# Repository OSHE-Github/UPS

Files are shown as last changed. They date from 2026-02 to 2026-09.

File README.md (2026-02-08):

# UPS

Uninterruptible Power Supply Hat for Raspberry Pi

This is still very early in the design phase and is not suitable for use.

*･゜ﾟ･*:.｡..｡.:*･'(*ﾟ▽ﾟ*)'･*:.｡. .｡.:*･゜ﾟ･*

## Copyright

- All code is licensed under the GPL 3.0 or later. You can view a copy of this license in LICENSE.code
- All hardware computer aided design "CAD files" are licensed under the CERN-OHL-S license. A copy of this license can be found in LICENSE.cad
- Some footprints are provided by the manufacturer or a third party source. They are licensed under their respective licenses.

Which licenses apply to which files will be clarified in a later commit. If you have questions please contact us.

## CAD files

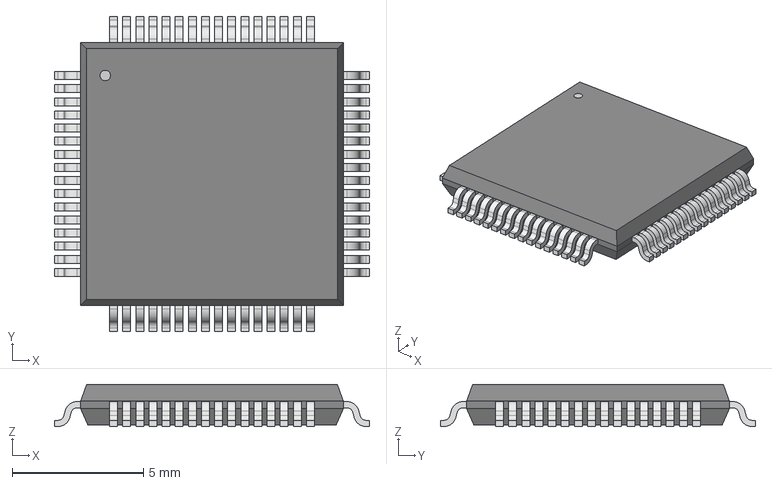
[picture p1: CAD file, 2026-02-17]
bloat/ul_STM32L152RCT6 (1)/LQFP64-10x10mm.step
12.0 x 12.0 x 1.60 mm

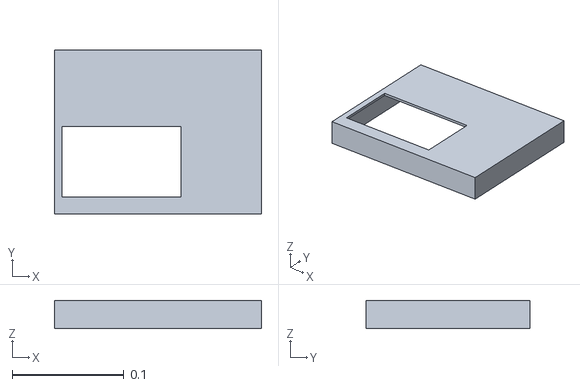
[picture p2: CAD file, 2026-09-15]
ecad/UPS-Case-V1-P2.stl
0.185 x 0.147 x 0.0254

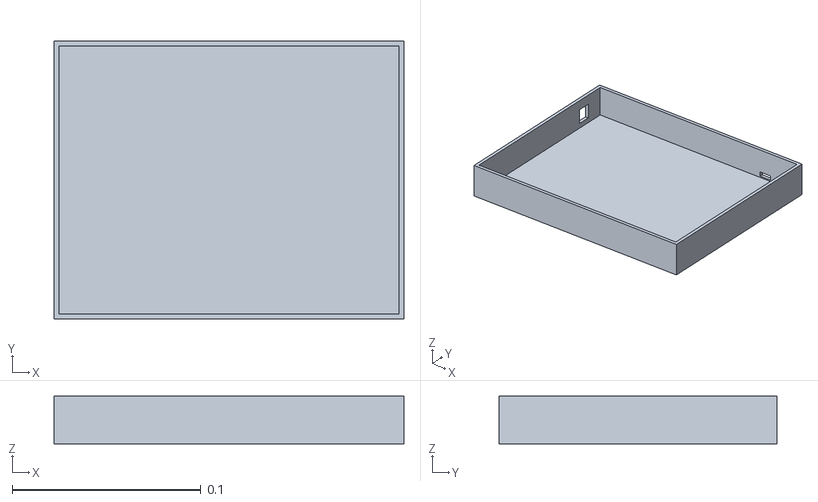
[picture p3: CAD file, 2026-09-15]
ecad/UPS-Case-V1-P1.stl
0.185 x 0.147 x 0.0254

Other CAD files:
bloat/ul_STM32L152RCT6 (1)/LQFP64-10x10mm.iges
bloat/ul_STM32L152RCT6 (1)/LQFP64-10x10mm.stl

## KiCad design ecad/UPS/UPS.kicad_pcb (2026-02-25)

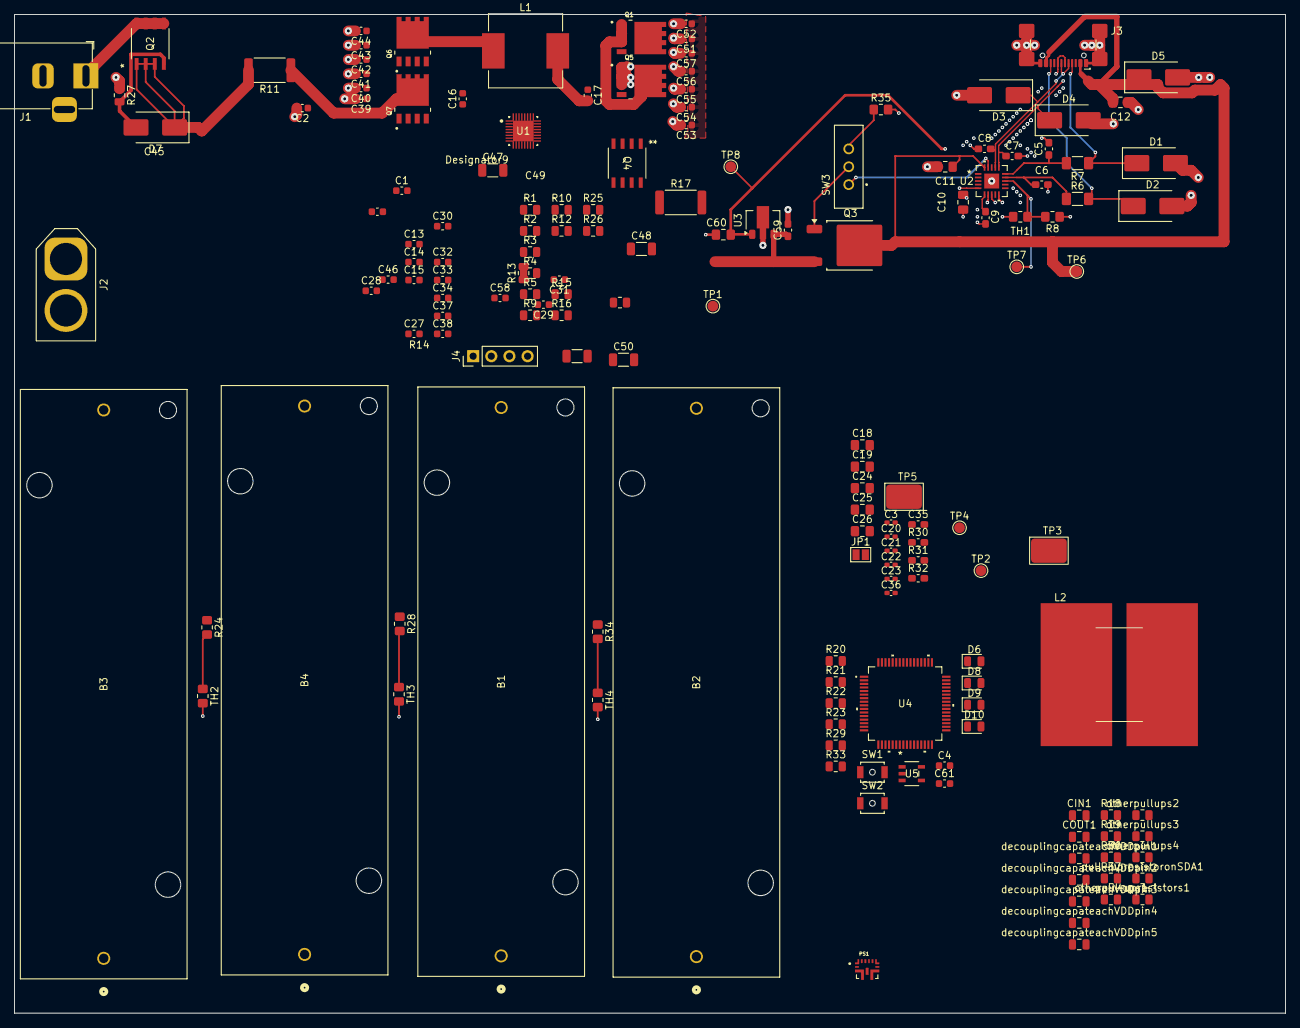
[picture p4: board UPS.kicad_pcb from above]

Board: 4 copper layers, 177.8 x 139.7 mm, 160 parts (0 on the bottom side), 77 nets.

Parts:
B1, B2, B3, B4: 1121; 1121_KEY
C1, C2: 100pF; C_0603_1608Metric
C3, C20, C21: .1uF; C_0402_1005Metric_Pad0.74x0.62mm_HandSolder
C4, C61: 0.1uf; C_0603_1608Metric
C5, C6: 390pF; C_0603_1608Metric_Pad1.08x0.95mm_HandSolder
C7, C8: 1nF; C_0603_1608Metric_Pad1.08x0.95mm_HandSolder
C9: 470pF; C_0603_1608Metric_Pad1.08x0.95mm_HandSolder
C10, C11, C12: 4.7uF; C_0805_2012Metric_Pad1.18x1.45mm_HandSolder
C13, C15: 33nF; C_0603_1608Metric
C14, C45: 10nF; C_0603_1608Metric
C16: 47nF; C_0603_1608Metric
C17: 47 nF; C_0603_1608Metric
C18, C19: 10uF; C_0805_2012Metric_Pad1.18x1.45mm_HandSolder
C22: 3.9nF; C_0402_1005Metric_Pad0.74x0.62mm_HandSolder
C23: 80pF; C_0402_1005Metric_Pad0.74x0.62mm_HandSolder
C24, C25, C26: 22uF; C_0805_2012Metric_Pad1.18x1.45mm_HandSolder
C27: 1uF; C_0603_1608Metric
C28: 15pF; C_0603_1608Metric
C29: 33pF; C_0603_1608Metric
C30: 1200 pF; C_0603_1608Metric
C31: 3.3nF; C_0603_1608Metric
C32: .1µF; C_0603_1608Metric
C33, C37, C39, C40, C41, C42, C43, C44, C51, C52, C53, C54, C55, C56, C57: 10µF; C_0603_1608Metric
C34, C38: 1µF; C_0603_1608Metric
C35: 2.2uF; C_0603_1608Metric_Pad1.08x0.95mm_HandSolder
C36: 1pF; C_0402_1005Metric_Pad0.74x0.62mm_HandSolder
C46: 1 nF; C_0603_1608Metric
C47, C48, C49, C50: 22µF; C_1206_3216Metric
C58: 2.2µF; C_0603_1608Metric
C59: 330nF; C_0603_1608Metric_Pad1.08x0.95mm_HandSolder
C60: 100nF; C_0805_2012Metric_Pad1.18x1.45mm_HandSolder
CIN1: 1uf; C_0805_2012Metric
COUT1: 1uf; C_0805_2012Metric
D1, D2: 6V; D_SMB_Handsoldering
D3, D4: 3.5V; D_SMB_Handsoldering
D5: 13V; D_SMB_Handsoldering
D6, D8, D9, D10: LED; LED_0805_2012Metric
D7: D_Zener; D_SMB_Handsoldering
J1: Barrel_Jack; BarrelJack_Horizontal
J2: Conn_01x02_Socket; AMASS_XT60-F_1x02_P7.20mm_Vertical
J3: USB_C_Receptacle_USB2.0_16P; USB_C_Receptacle_GCT_USB4110
J4: PROG; PinHeader_1x04_P2.54mm_Vertical
JP1: SolderJumper_2_Open; SolderJumper-2_P1.3mm_Open_Pad1.0x1.5mm
L1: 2.2µH; L_Vishay_IHLP-4040
L2: 4.7uH; IND_ETQP8M4R7JFA
PS1: TPS61288LRQQR; CONV_TPS61288LRQQR
Q1, Q5, Q6, Q7: CSD18540Q5B; TRANS_CSD18540Q5B
Q2: Q_PMOS_DGS; FDS6681Z_OSI-M
Q3: IRLR7843TRPBF; TO-252-2
Q4: Q_PMOS_DGS; FDS6681Z_OSI
R1: 140k; R_0805_2012Metric
R2, R14, R36, R37: 10k; R_0805_2012Metric
R3: 56k; R_0805_2012Metric
R4, R19, R27: 100k; R_0805_2012Metric
R5, R15, R16: 10; R_0805_2012Metric
R6, R7: 2; R_1206_3216Metric_Pad1.30x1.75mm_HandSolder
R8, R24, R28, R34, R35: 68.1k; R_0805_2012Metric_Pad1.20x1.40mm_HandSolder
R9, R10: 4.99; R_0805_2012Metric
R11, R17: .01; R_2512_6332Metric
R12: 2.2; R_0805_2012Metric
R13: 16.9k; R_0805_2012Metric
R18: 15k; R_0805_2012Metric
R20, R21, R22, R33: 1.5K; R_0805_2012Metric
R23, R29: 10K; R_0805_2012Metric
R25: 60k; R_0805_2012Metric
R26: 20k; R_0805_2012Metric
R30: 8.25k; C_0603_1608Metric_Pad1.08x0.95mm_HandSolder
R31: 14.3k; C_0603_1608Metric_Pad1.08x0.95mm_HandSolder
R32: 107k; C_0603_1608Metric_Pad1.08x0.95mm_HandSolder
SW1, SW2: SW_Push; SW_SPST_B3U-1000P-B
SW3: SW_DPDT_x2; SW_EG1218
TH1, TH2, TH3, TH4: B57471V2104J062; R_0805_2012Metric_Pad1.20x1.40mm_HandSolder
TP1: 5vTest; TestPoint_Pad_D1.5mm
TP2: AGNDTest; TestPoint_Pad_D1.5mm
TP3: PGNDTest; TespointBig
TP4: Enable; TestPoint_Pad_D1.5mm
TP5: Vin; TespointBig
TP6: VBus; TestPoint_Pad_D1.5mm
TP7: NTC1; TestPoint_Pad_D1.5mm
TP8: 5V_REG; TestPoint_Pad_D1.5mm
U1: BQ25730RSNR; RSN0032B-IPC_A
U2: MPQ5031GRE-0001-AEC1-P; QFN-20_MPQ5031_MNP
U3: L78L05_SOT89; SOT-89-3
U4: STM32L152RCT6; LQFP64-10x10mm
U5: AP2112K-3.3TRG1; SOT_RG1_DIO
decouplingcapateachVDDpin1, decouplingcapateachVDDpin2, decouplingcapateachVDDpin3, decouplingcapateachVDDpin4, decouplingcapateachVDDpin5: 100nF; C_0805_2012Metric
otherpullups1, otherpullups2, otherpullups3, otherpullups4: 10k; R_0805_2012Metric
pull-upresistoronSDA1: 4.7k; R_0805_2012Metric
pull-upresistors1: 4.7k; R_0805_2012Metric

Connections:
3.3V: C61.2, COUT1.1, R19.2, R29.1, R36.2, R37.2, SW1.1, U4.13 (VDDA), U4.19 (VDD_4), U4.32 (VDD_1), U4.48 (VDD_2), U4.64 (VDD_3), U5.5 (VOUT), decouplingcapateachVDDpin1.2, decouplingcapateachVDDpin2.2, decouplingcapateachVDDpin3.2, decouplingcapateachVDDpin4.2, decouplingcapateachVDDpin5.2, otherpullups1.2, otherpullups2.2, otherpullups3.2, otherpullups4.2, pull-upresistoronSDA1.1, pull-upresistors1.1
+3.3V: J4.1, R24.1, R28.1, R34.1
+5V: C10.1, C60.2, CIN1.1, R8.1, TP8.1, U2.5 (I2C_MODE), U2.7 (VCC), U3.1 (OUT), U5.1 (VIN), U5.3 (EN)
/BoostConvertor/VSYS: C49.1, C50.1
/BoostConvertor/Vcc: C35.1, PS1.6 (EN), PS1.11 (VCC), TP4.1
/Charger/CMPIN: R18.1, R19.1, U1.14 (CMPIN)
/Charger/OTG/VAP: U1.5 (OTG_VAP), U4.22 (PA6), otherpullups3.1
/Charger/PROCHOT_N: U1.11 (PROCHOT_N), U4.14 (PA0-WKUP1), otherpullups1.1
/Charger/bat_th1: R24.2, TH2.1, U4.34 (PB13)
/Charger/bat_th2: R28.2, TH3.1, U4.35 (PB14)
/Charger/bat_th3: R34.2, TH4.1, U4.36 (PB15)
/Charger/chrg_ok: U1.4 (CHRG_OK), U4.15 (PA1), otherpullups2.1
/Charger/cmp_out: U1.15 (CMPOUT), U4.23 (PA7), otherpullups4.1
/Output/CC1: D1.1 (K), J3.A5 (CC1), R7.1
/Output/CC2: D2.1 (K), J3.B5 (CC2), R6.2
/Output/D+: C7.1, D4.1 (K), J3.A6 (D+), J3.B6 (D+), U2.16 (DP)
/Output/D-: C8.1, D3.1 (K), J3.A7 (D-), J3.B7 (D-), U2.17 (DM)
/Output/SCL: U1.13 (SCL), U2.2 (SCL), U4.61 (PB8), pull-upresistors1.2
/Output/SDA: U1.12 (SDA), U2.1 (SDA), U4.62 (PB9), pull-upresistoronSDA1.2
/Output/VBUS_in: C3.1, C24.1, C25.1, C26.1, C59.1, PS1.5 (VOUT), Q3.3 (S), R32.1, TP1.1, U3.3 (IN)
/Output/VBUS_out: C11.2, C12.1, D5.1 (K), J3.A4 (VBUS), J3.A9 (VBUS), J3.B4 (VBUS), J3.B9 (VBUS), Q3.2 (D), TP6.1, U2.20 (VBUS_P)
/controller/vsel1: R36.1, U4.43 (PA10)
/controller/vsel2: R37.1, U4.44 (PA11)
AGND: C23.2, C35.2, C36.2, PS1.10 (AGND), R30.2, R31.2, TP2.1
BTST1: C16.1, U1.30 (BTST1)
BTST2: C17.1, U1.25 (BTST2)
COMP1: C29.2, R13.1, U1.16 (COMP1)
COMP2: C28.2, R14.1, U1.17 (COMP2)
ILIM_HIZ: R3.1, R4.2, U1.6 (ILIM_HIZ)
NRST: C4.1, R29.2, SW2.2, U4.7 (NRST)
unnamed: C20.1, L2.2, PS1.4 (SW), PS1.9 (SW)
unnamed: C22.1, R30.1
unnamed: C27.2, R12.1
unnamed: C30.2, R14.2
unnamed: C31.2, R13.2
unnamed: D6.2 (A), U4.21 (PA5)
unnamed: D6.1 (K), R33.1
unnamed: D7.2 (A), Q2.4, R27.2
unnamed: D8.2 (A), U4.16 (PA2)
unnamed: D8.1 (K), R20.1
unnamed: D9.2 (A), U4.17 (PA3)
unnamed: D9.1 (K), R21.1
unnamed: D10.2 (A), U4.20 (PA4)
unnamed: D10.1 (K), R22.1
unnamed: J1.1, Q2.5, Q2.6, Q2.7, Q2.8
unnamed: B1.2, B2.2, B3.2, B4.2, C32.1, C33.1, C37.1, J2.1, R16.1, R17.2, U1.19 (SRN)
unnamed: C18.1, C19.1, C21.1, JP1.2 (B), L2.1, PS1.7 (VIN), TP5.1
unnamed: C20.2, PS1.8 (BST)
unnamed: C22.2, C23.1, PS1.2 (COMP)
unnamed: C36.1, PS1.1 (FB), R31.1, R32.2
unnamed: Q3.1 (G), SW3.2 (B)
unnamed: SW3.1 (A), U2.19 (VDRV)
unnamed: R35.1, SW3.3 (C)
unnamed: C13.1, C14.2, C45.1, C46.1, Q7.5_6_7_8, R9.1, R11.1, U1.2 (ACN)
unnamed: Q4.4, U1.21 (BATDRV_N)
unnamed: R25.2, R26.1, U1.18 (CELL_BATPRESZ)
unnamed: Q1.4, U1.24 (HIDRV2)
unnamed: C2.1, R1.1, U1.8 (IADPT)
unnamed: C1.1, U1.9 (IBAT)
unnamed: Q6.4, U1.29 (LODRV1)
unnamed: Q5.4, U1.26 (LODRV2)
unnamed: R2.1, U1.10 (PSYS)
unnamed: C32.2, C34.1, Q4.5, Q4.6, Q4.7, Q4.8, R15.2, R17.1, U1.20 (SRP)
unnamed: C17.2, L1.2, Q1.1, Q1.2, Q1.3, Q5.5_6_7_8, U1.23 (SW2)
unnamed: C5.1, R7.2, U2.15 (CC1)
unnamed: C6.1, R6.1, U2.14 (CC2)
unnamed: R8.2, TH1.1, TP7.1, U2.13 (NTC)
unnamed: C9.1, U2.6 (VDD)
unnamed: C61.1, R23.2, SW1.2, U4.60 (BOOT0)
PA13_SWDIO: J4.2, U4.46 (PA13)
PA14_SWCLK: J4.3, U4.49 (PA14)
PGND: B1.1, B2.1, B3.1, B4.1, C1.2, C2.2, C3.2, C4.2, C5.2, C6.2, C7.2, C8.2, C9.2, C10.2, C11.1, C12.2, C13.2, C15.1, C18.2, C19.2, C21.2, C24.2, C25.2, C26.2, C27.1, C28.1, C29.1, C30.1, C31.1, C33.2, C34.2, C37.2, C38.2, C39.2, C40.2, C41.2, C42.2, C43.2, C44.2, C45.2, C46.2, C47.2, C48.2, C49.2, C50.2, C51.2, C52.2, C53.2, C54.2, C55.2, C56.2, C57.2, C58.2, C59.2, C60.1, CIN1.2, COUT1.2, D1.2 (A), D2.2 (A), D3.2 (A), D4.2 (A), D5.2 (A), J1.2, J2.2, J3.A1 (GND), J3.A12 (GND), J3.B1 (GND), J3.B12 (GND), J3.S1 (SHIELD), J4.4, PS1.3 (PGND), Q5.1, Q5.2, Q5.3, Q6.1, Q6.2, Q6.3, Q7.4, R1.2, R2.2, R3.2, R18.2, R20.2, R21.2, R22.2, R23.1, R26.2, R27.1, R33.2, R35.2, SW2.1, TH1.2, TH2.2, TH3.2, TH4.2, TP3.1, U1.27 (PGND), U1.31 (HIDRV1), U1.33 (Thermal_Pad), U2.8 (GND), U2.10 (GPIO4), U2.21 (EPAD), U3.2 (GND), U4.12 (VSSA), U4.18 (VSS_4), U4.31 (VSS_1), U4.47 (VSS_2), U4.63 (VSS_3), U5.2 (GND), decouplingcapateachVDDpin1.1, decouplingcapateachVDDpin2.1, decouplingcapateachVDDpin3.1, decouplingcapateachVDDpin4.1, decouplingcapateachVDDpin5.1
PMOS_IN_GATE: C14.1, C15.2, C39.1, C40.1, C41.1, C42.1, C43.1, C44.1, D7.1 (K), Q2.1, Q2.2, Q2.3, R10.2, R11.2, R12.2, U1.1 (VBUS), U1.3 (ACP)
PMOS_OUT_GATE: C47.1, C48.1, C51.1, C52.1, C53.1, C54.1, C55.1, C56.1, C57.1, JP1.1 (A), Q1.5_6_7_8, Q4.1, Q4.2, Q4.3, U1.22 (VSYS)
REGN: C58.1, R5.1, U1.28 (REGN)
SW1: C16.2, L1.1, Q6.5_6_7_8, Q7.1, Q7.2, Q7.3, U1.32 (SW1)
VDDA: C38.1, R4.1, R5.2, R25.1, U1.7 (VDDA)

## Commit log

2026-02-08 Add CAD files license
2026-02-08 Add PD IC and started USB C protection/bypass
    [UPS.kicad_sch, UPSOutput.kicad_sch]
2026-02-09 PD thermistor and more bypass caps
    [UPSOutput.kicad_sch]
2026-02-09 Add diode footprints
    [UPSOutput.kicad_sch]
2026-02-10 Updated Kicad_sym
2026-02-13 UPSOutput cleanup
    [UPSOutput.kicad_sch]
2026-02-17 mcJohn
    STM32L152RCT6 schematic and CubeIDE project
    [Charger.kicad_sch, LQFP64-10x10mm.iges, LQFP64-10x10mm.step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]
2026-02-21 added components to bom
    [UPSOutput.kicad_sch]
2026-02-21 Made Power Net Class and set up board parameters and constraints
    [UPS.kicad_pcb, controller.kicad_sch]
2026-02-23 Moved most components where they belong-ish
    Barrel Jack's on the end as well as battery connector for now. The MOSFET's need to be really close to the caps in the charger module
    [Charger.kicad_sch, UPS.kicad_pcb, UPSOutput.kicad_sch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]
2026-02-24 More PCB Progress, more to come tomorrow morning
    [Charger.kicad_sch, UPS.kicad_pcb]
2026-02-24 Last minute footprint fixes on charger module
    [Charger.kicad_sch, UPS.kicad_pcb]
2026-02-24 boot0 fix
    [controller.kicad_sch]
2026-02-24 minor things
    [controller.kicad_sch]
2026-02-24 Add thermistors for batteries and link signals
    [Charger.kicad_sch, UPS.kicad_pcb, UPS.kicad_sch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]
2026-02-24 found a short
    [controller.kicad_sch]
2026-02-24 Start routing USB output on PCB
    [Charger.kicad_sch, UPS.kicad_pcb, UPSOutput.kicad_sch]
2026-02-24 Update PCB from schematic
    [UPS.kicad_pcb]
2026-02-24 PCB Outline
    [UPS.kicad_pcb, controller.kicad_sch]
2026-02-24 Add switch
    [BoostConvertor.kicad_sch, UPS.kicad_pcb, UPSOutput.kicad_sch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]
2026-02-25 Output section of PCB
    [BoostConvertor.kicad_sch, UPS.kicad_pcb, UPSOutput.kicad_sch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]
2026-02-25 Add extra via
    [UPS.kicad_pcb]
2026-02-25 Random PCB cleanup
    [UPS.kicad_pcb]
2026-02-25 Need to finish some traces, DRC warnings are keeping me from routing to the BQ,
    [BoostConvertor.kicad_sch, Charger.kicad_sch, UPS.kicad_pcb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]
2026-02-25 push button foot print
    [UPS.kicad_pcb, controller.kicad_sch]
2026-02-25 replaced solder jumper with resistor
    [BoostConvertor.kicad_sch]
2026-02-25 Updated Footprints
    [BoostConvertor.kicad_sch]
2026-02-25 Did some routing, need to figure out how to route to BQ while appeasing DRC
    [Charger.kicad_sch, UPS.kicad_pcb]
2026-02-25 More PCB routing
    [BoostConvertor.kicad_sch, UPS.kicad_pcb, controller.kicad_sch]
2026-02-26 Introduce fuses and a bit more routing
    [BoostConvertor.kicad_sch, Charger.kicad_sch, UPS.kicad_pcb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]
2026-02-26 More PCB Routing!!!!!
    Most of the MCU is done
    [Charger.kicad_sch, UPS.kicad_pcb, UPS.kicad_sch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]
2026-02-26 added vbat_sense to DAC
    [controller.kicad_sch]
2026-02-26 last min pin rearangement
    [UPS.kicad_pcb, UPS.kicad_sch, controller.kicad_sch]
2026-02-26 VBATSENSE divider put in and some routing
    Little more routing, complete by tonight
    [BoostConvertor.kicad_sch, Charger.kicad_sch, UPS.kicad_pcb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]
2026-02-27 DRC is angry but everything has a route
    Angry about a lot of the vias in the top right specifically, there's A LOT of issues with clearance I want to look at, taking another break for now.
    [UPS.kicad_pcb, UPSOutput.kicad_sch, controller.kicad_sch]
2026-02-28 Final board for now (Pre Spring Break)
    [UPS.kicad_pcb]
2026-09-17 Pins for thermistors, removed battery connector
    [UPS.kicad_sch]
